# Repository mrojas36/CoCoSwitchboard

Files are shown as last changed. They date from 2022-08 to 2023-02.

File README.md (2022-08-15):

# CoCoSwitchboard
Membrane Replacement for TRS-80 Color Computer Keyboards

## Color Computer 3 Switchboard
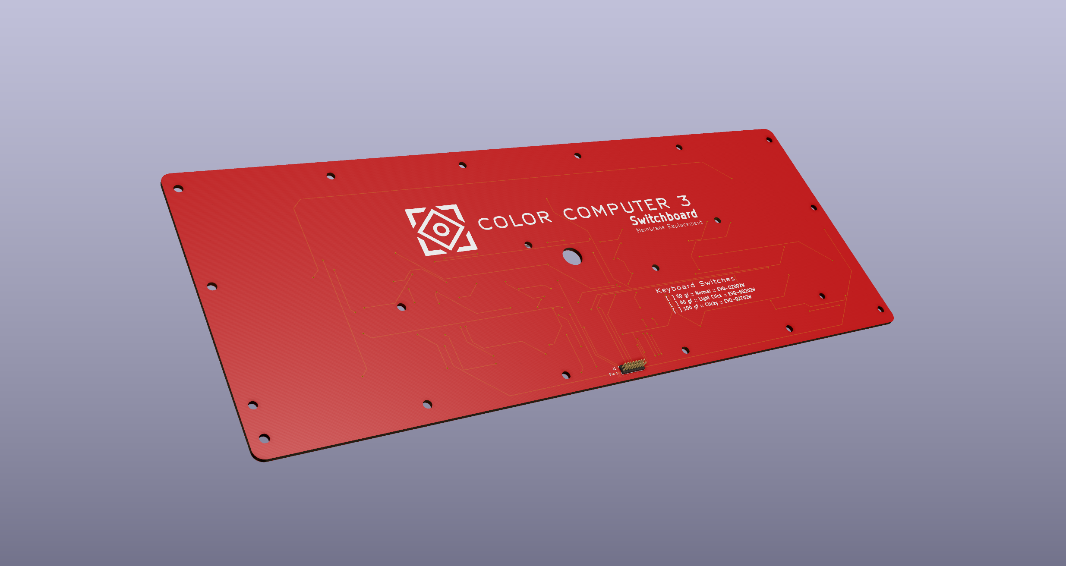
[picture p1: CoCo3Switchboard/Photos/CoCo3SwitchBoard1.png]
CoCo3Switchboard

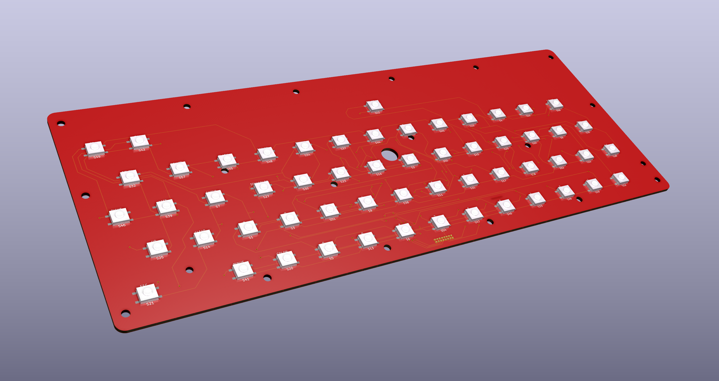
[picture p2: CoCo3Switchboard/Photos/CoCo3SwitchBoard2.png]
CoCo3Switchboard


## Color Computer 2 Switchboard
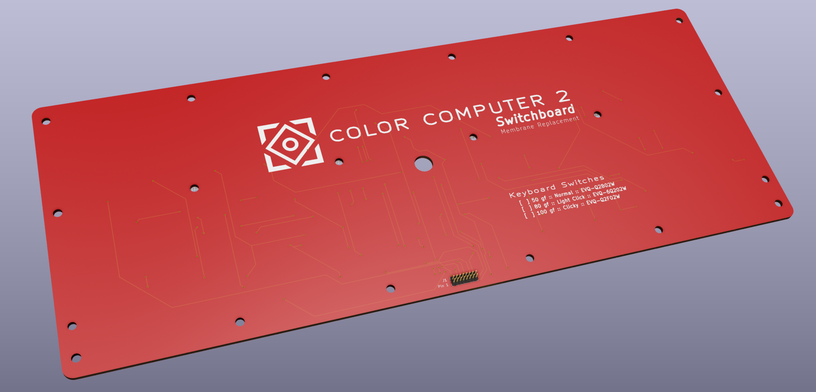
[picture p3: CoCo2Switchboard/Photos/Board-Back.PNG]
CoCo2Switchboard

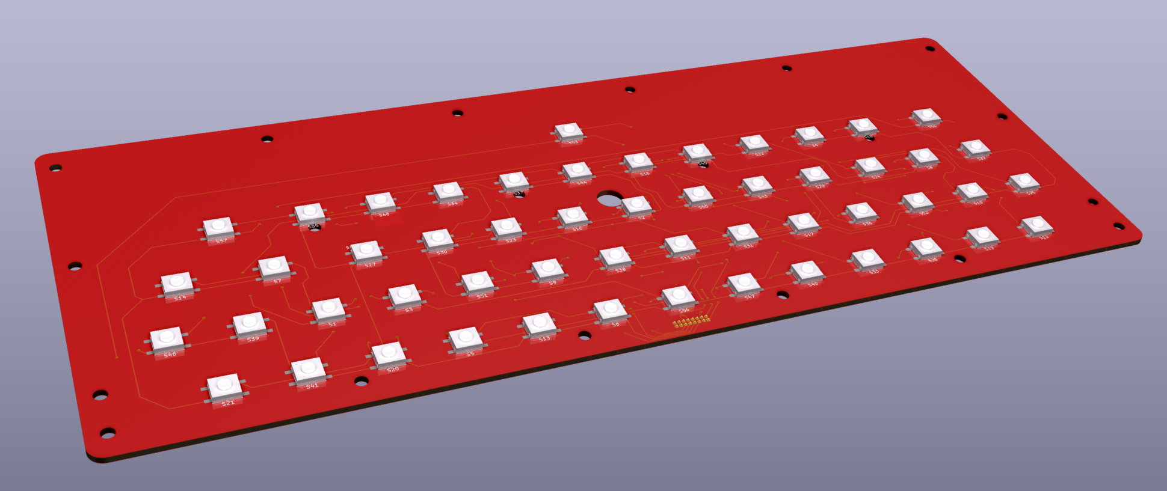
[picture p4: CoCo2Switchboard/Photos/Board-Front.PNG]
CoCo2Switchboard


## Color Computer 1 Switchboard
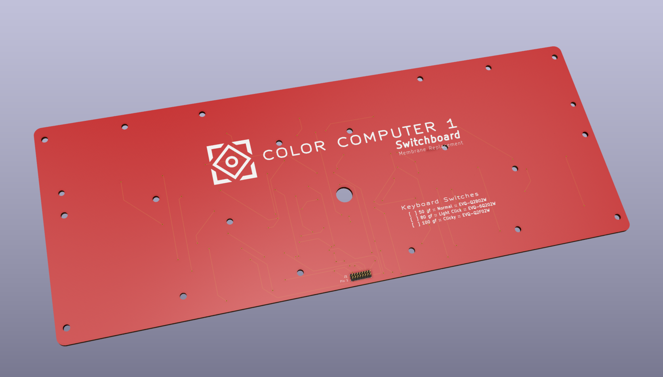
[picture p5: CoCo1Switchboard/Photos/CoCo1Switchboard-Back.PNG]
CoCo1Switchboard

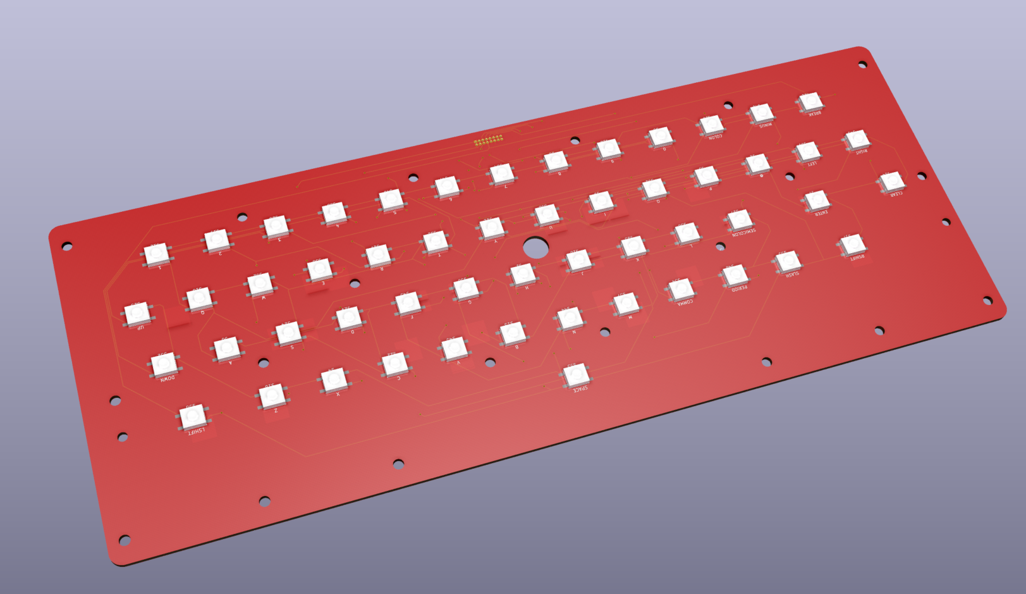
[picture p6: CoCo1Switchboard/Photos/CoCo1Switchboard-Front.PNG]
CoCo1Switchboard


## Keyboard Adapter
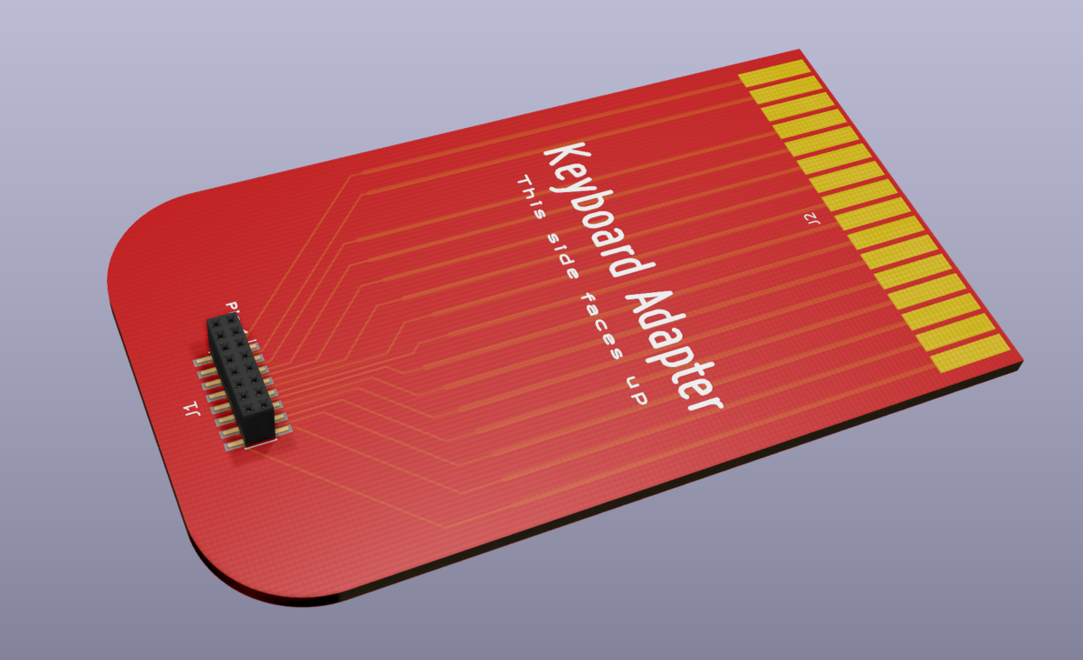
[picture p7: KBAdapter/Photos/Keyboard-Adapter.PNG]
Keyboard Adapter


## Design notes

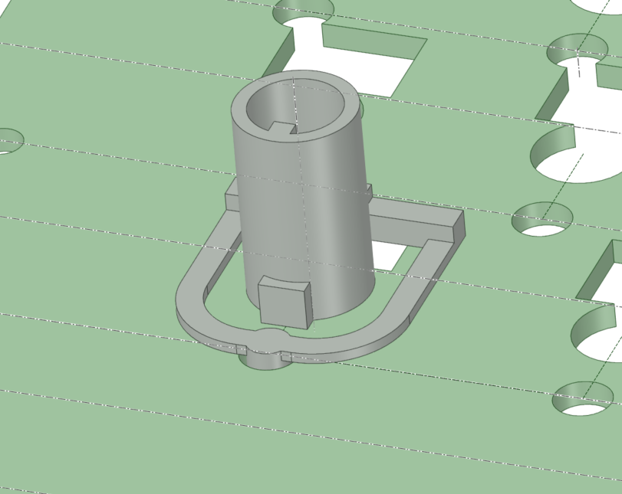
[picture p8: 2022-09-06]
CoCo3Switchboard/Photos/New-Spacer-Design.png

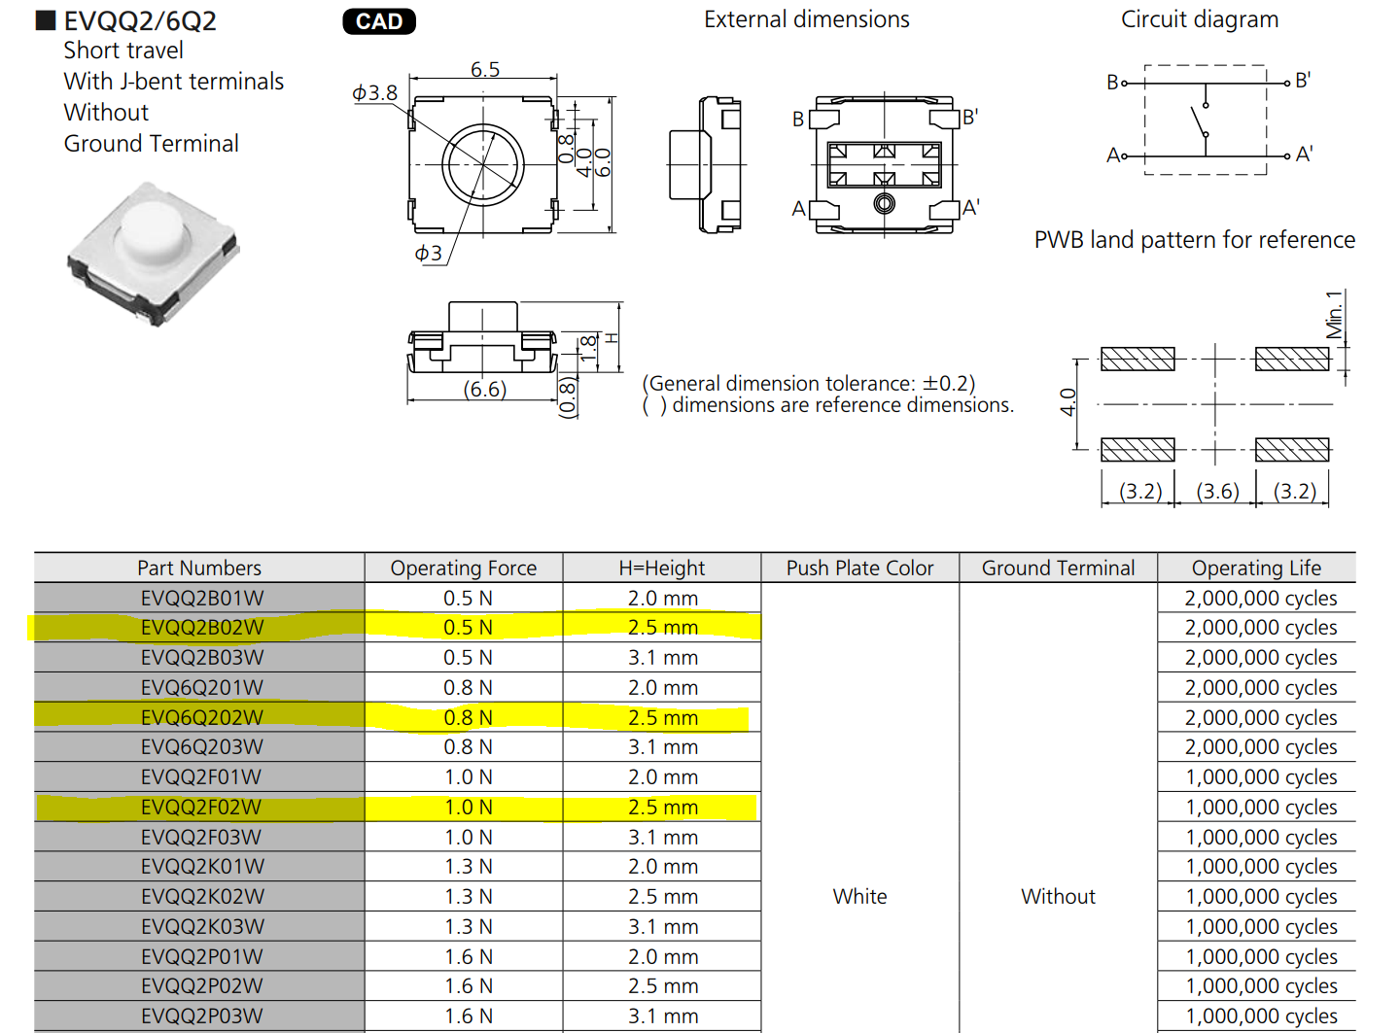
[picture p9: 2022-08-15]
CoCo3Switchboard/Photos/Switches.PNG

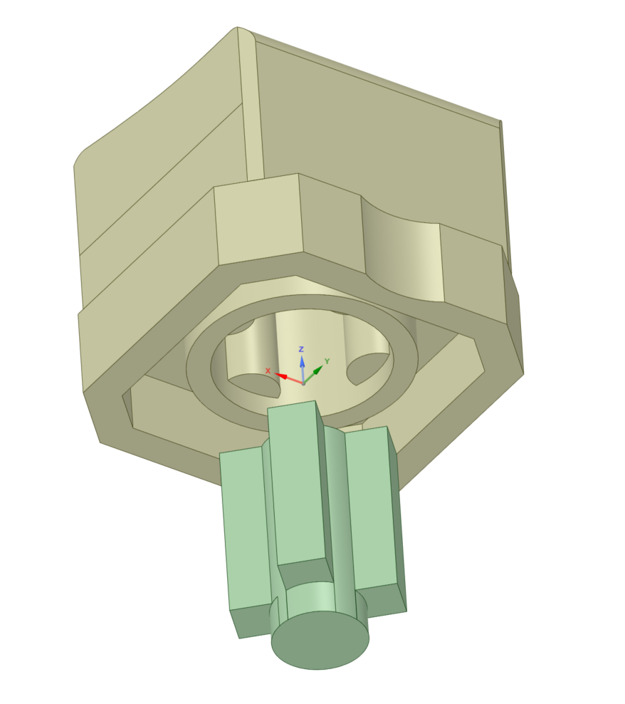
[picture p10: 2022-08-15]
CoCo1Switchboard/Photos/Key-Post-Not-Inserted.PNG

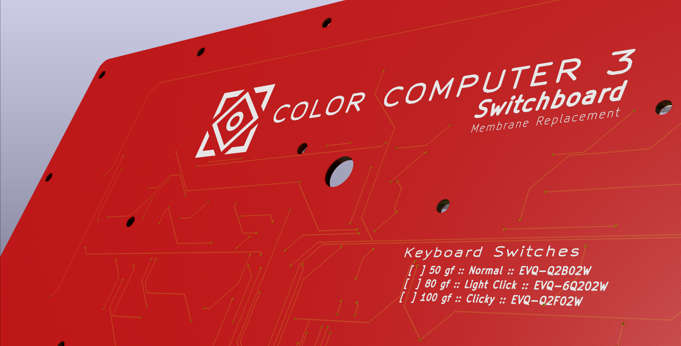
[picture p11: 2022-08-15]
CoCo3Switchboard/Photos/CoCo3SwitchBoard7.png

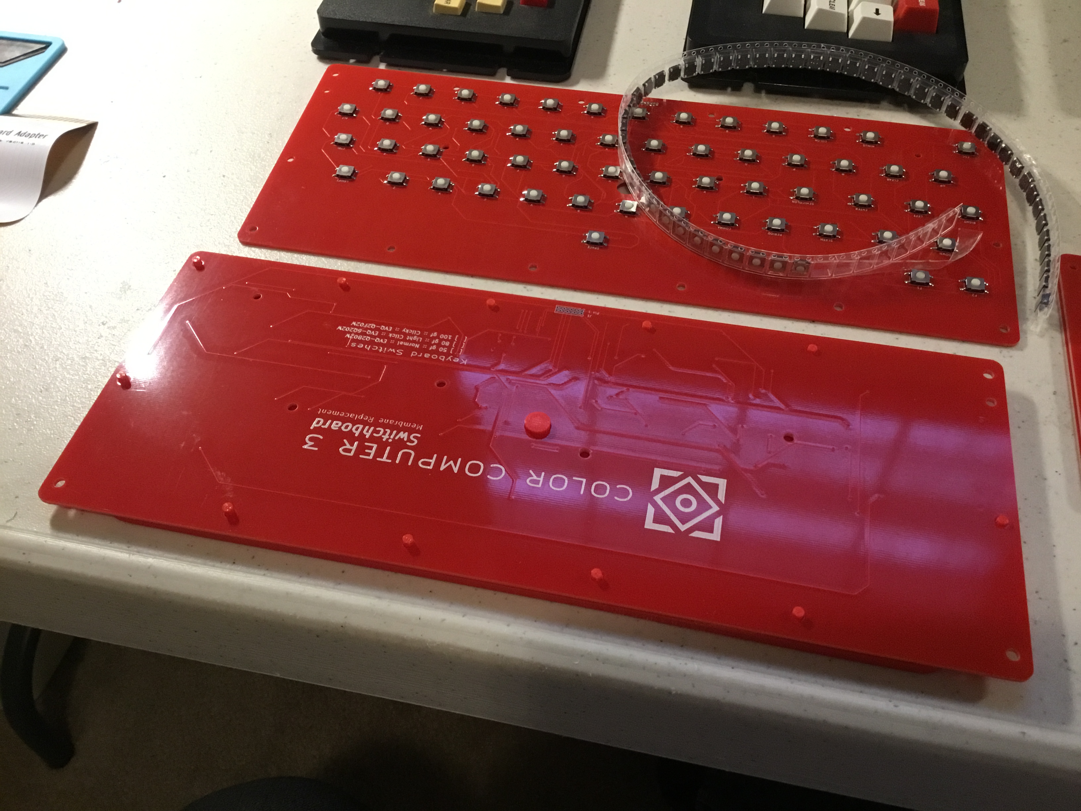
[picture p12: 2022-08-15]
CoCo3Switchboard/Photos/Jib3.JPG

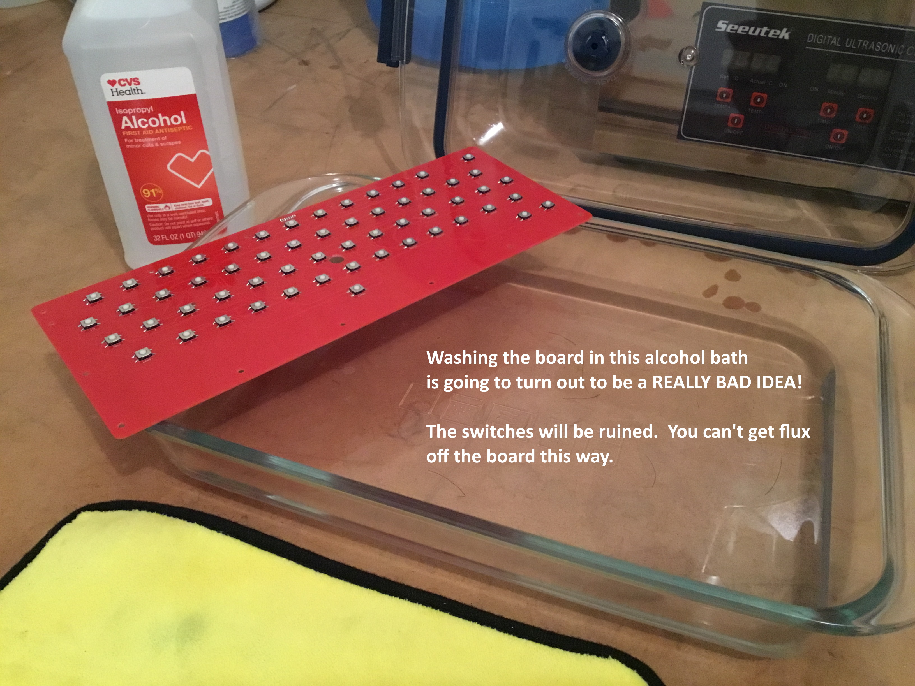
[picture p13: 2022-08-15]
CoCo3Switchboard/Photos/Wash.JPG

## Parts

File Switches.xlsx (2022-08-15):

Index | Quantity | Part Number | Manufacturer Part Number | Description | Customer Reference | Backorder | Unit Price | Extended Price | Force | Total | 57
1 | 10 | EG4620CT-ND | TL3315NF100Q | SWITCH TACTILE SPST-NO 0.05A 15V |  | 0 | 0.144 | $1.44 | 100gf | 8.208
2 | 10 | CKN10879CT-ND | PTS530 GN055 SMTR LFS | SWITCH TACTILE SPST-NO 0.05A 12V |  | 0 | 0.208 | $2.08 | 100gf | 11.856
3 | 10 | CKN10777CT-ND | KXT 311 LHS | SWITCH TACTILE SPST-NO 0.02A 15V |  | 0 | 0.211 | $2.11 | 100gf | 12.027
4 | 10 | P12937SCT-ND | EVQ-Q2F03W | SWITCH TACTILE SPST-NO 0.02A 15V | 3.1mm | 0 | 0.272 | $2.72 | 100gf | 15.504
5 | 10 | P12970SCT-ND | EVQ-Q2F02W | SWITCH TACTILE SPST-NO 0.02A 15V | 2.5mm | 0 | 0.272 | $2.72 | 100gf | 15.504
1 | 10 | P124393CT-ND | EVQ-6Q202W | 6MM SQUARE THIN TYPE SMD LTSW | 2.5mm | 0 | $0.23 | $3.98 | 80gf | 13.0359
2 | 10 | P12931SCT-ND | EVQ-Q2B02W | SWITCH TACTILE SPST-NO 0.02A 15V | 2.5mm | 0 | $0.23 | $2.72 | 50gf | 13.2867
6 | 10 | CKN12218-1-ND | PTS526 SM08 SMTR2 LFS | TACT 5.2 X 5.2, 0.8 MM H, 160GF, |  | 0 | 0.112 | $1.12 | 160gf | 6.384
7 | 10 | 2508-R-667834CT-ND | R-667834 | SWITCH TACTILE, SPST-NO, 0.05A 1 |  | 0 | 0.141 | $1.41 | 163gf | 8.037
8 | 10 | 2508-R-667995CT-ND | R-667995 | SWITCH TACTILE, SPST-NO, 0.02A 1 |  | 0 | 0.179 | $1.79 | 163gf | 10.203
9 | 10 | CKN10809CT-ND | PTS540JM035SMTRLFS | SWITCH TACTILE SPST-NO 0.05A 12V |  | 0 | 0.174 | $1.74 | 160gf | 9.918
 |  |  |  |  |  |  | Subtotal | $17.13
 |  |  |  |  |  |  |  |  | 57 | 0.154 | 8.778
 |  |  |  |  |  |  |  |  |  |  | 5.16
 |  |  |  |  |  |  |  |  |  |  | 13.938

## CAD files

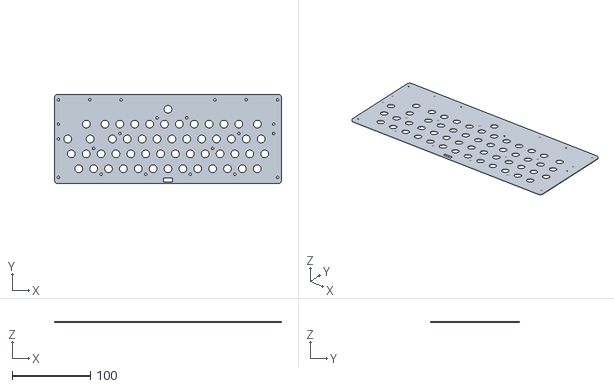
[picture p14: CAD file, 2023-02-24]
CoCo1Switchboard/Objects/Coco1-Spacer.stl
290.0 x 114.0 x 1.70

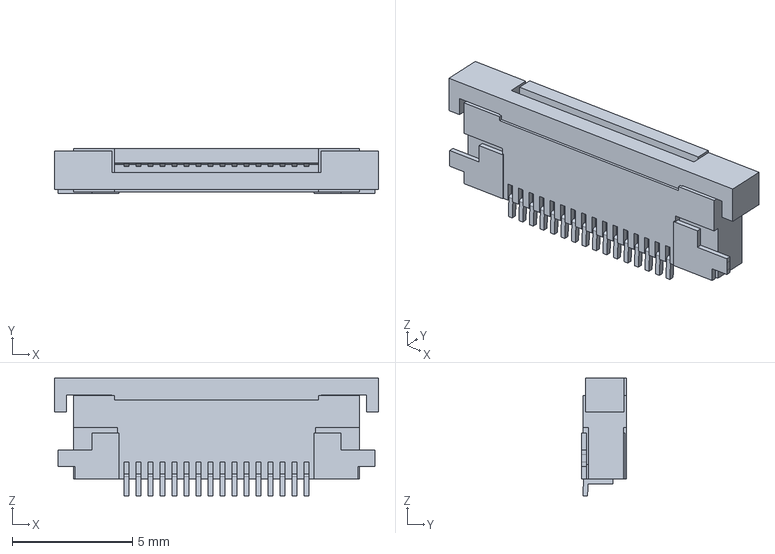
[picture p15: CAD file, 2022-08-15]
CoCo1Switchboard/ssfv16r_4stlf.stp
13.5 x 1.87 x 4.90 mm

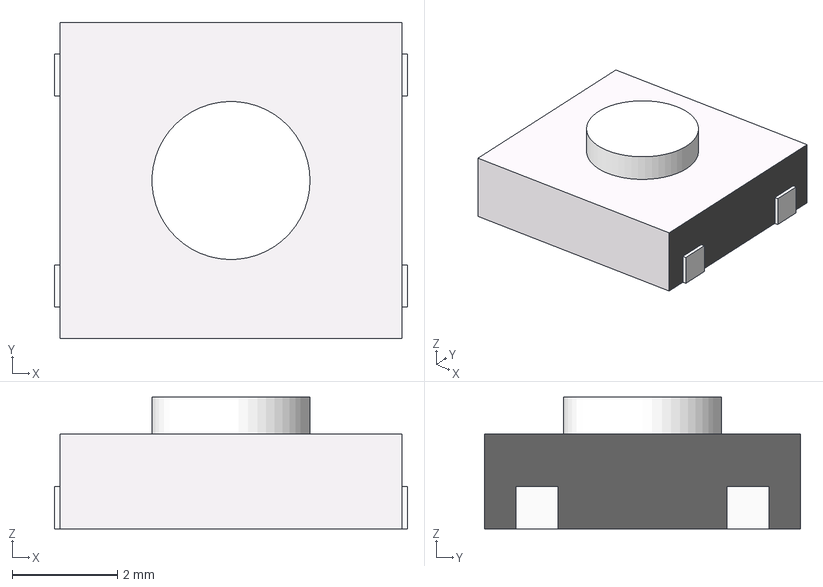
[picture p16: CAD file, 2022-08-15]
CoCo2Switchboard/Datasheets/EVQQ2-Switch.step
6.70 x 6.00 x 2.50 mm
Sketch
Plunger
Sketch002
SolderPad1
SolderPad2
SolderPad3
SolderPad4

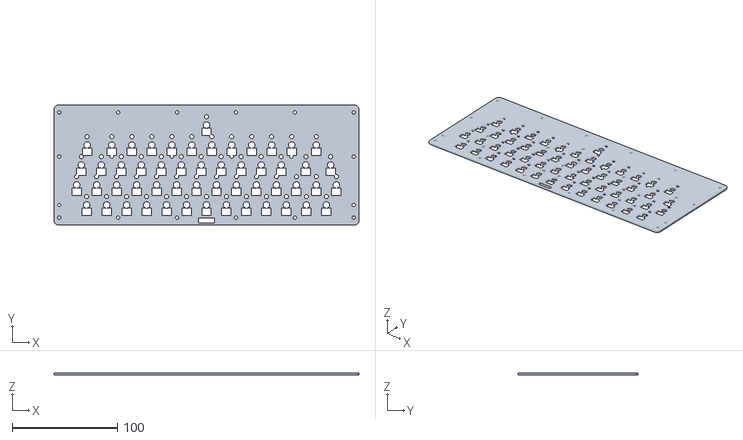
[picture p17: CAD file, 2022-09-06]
CoCo2Switchboard/Objects/Coco2Spacer-NewDesign.stl
290.0 x 114.0 x 1.80

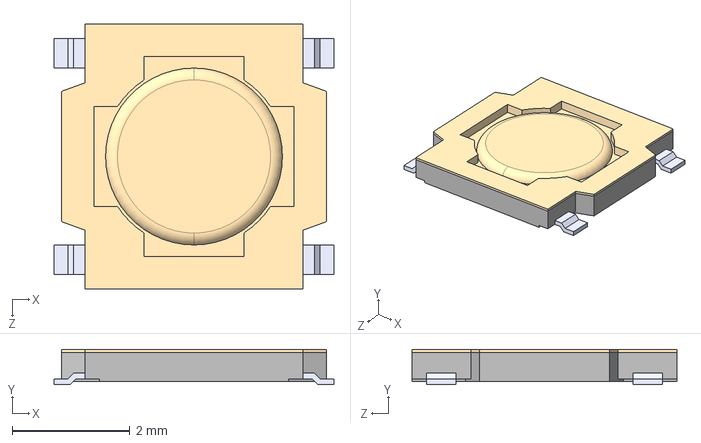
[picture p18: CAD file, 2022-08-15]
CoCo2Switchboard/TL3315NF100Q.step
4.75 x 0.6 x 4.50 mm

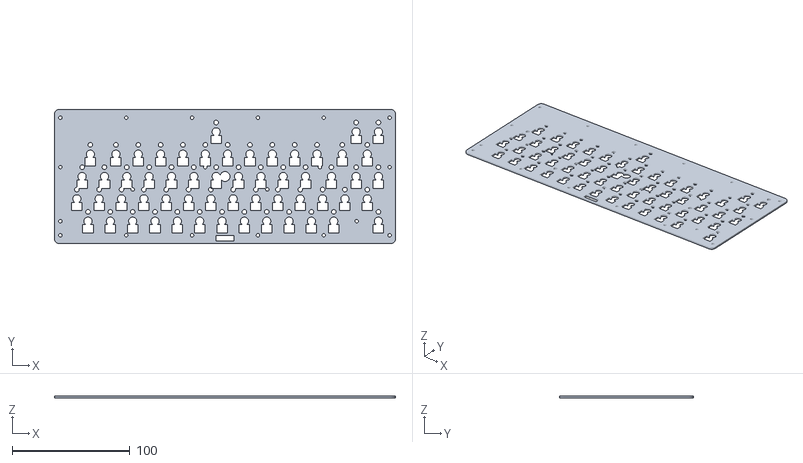
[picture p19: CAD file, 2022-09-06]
CoCo3Switchboard/Objects/Spacer.stl
290.0 x 114.0 x 1.80

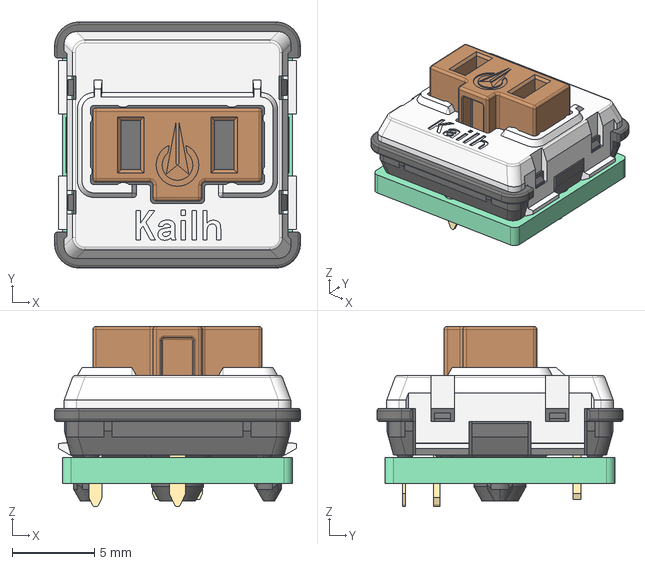
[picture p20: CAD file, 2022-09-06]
Designs/Kailh Choc Low Profile Switch.step
15.0 x 15.0 x 11.0 mm

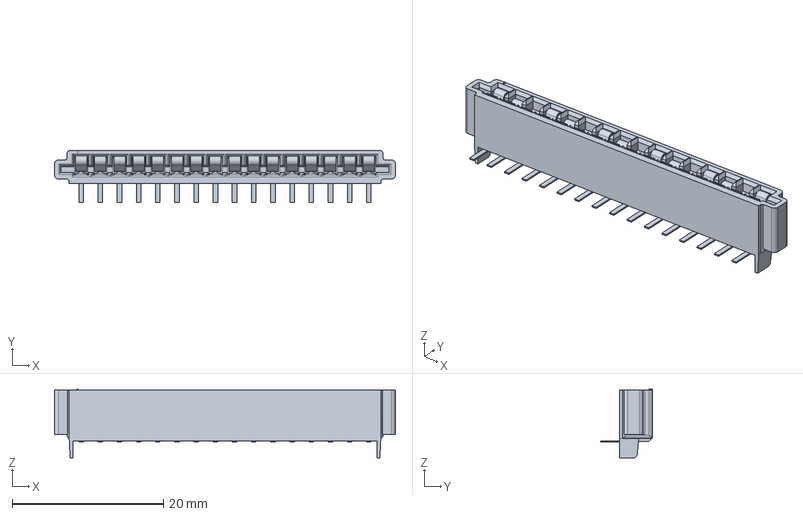
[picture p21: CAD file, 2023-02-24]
EdgeAdapter/c-6-520314-6-y-3d.stp
45.2 x 6.93 x 9.09 mm

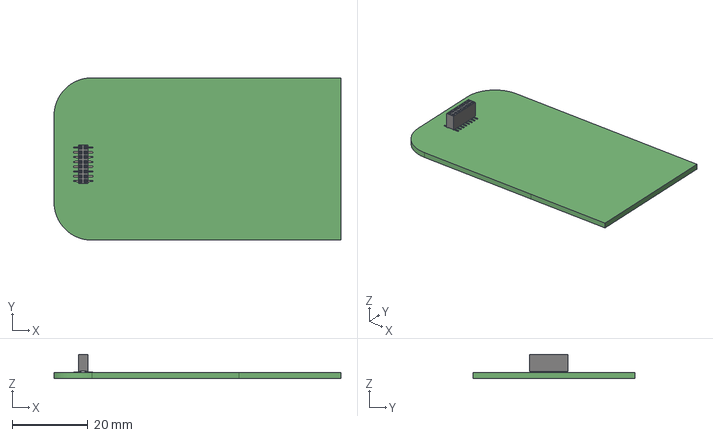
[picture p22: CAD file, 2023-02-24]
KBAdapter/KBAdapter.step
76.0 x 43.0 x 6.47 mm

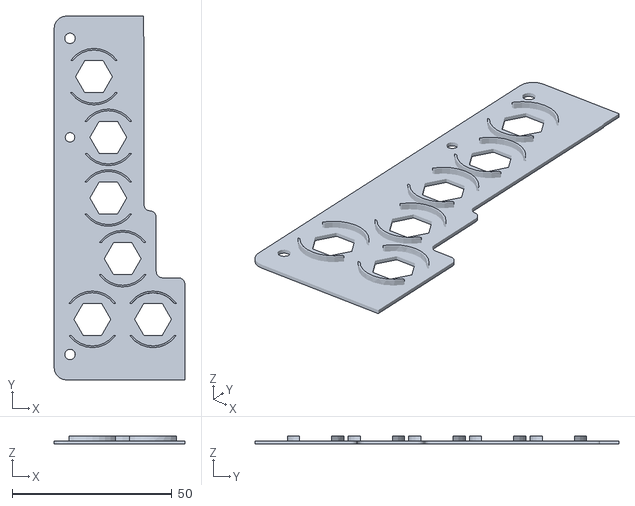
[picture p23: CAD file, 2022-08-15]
CoCo1Switchboard/Objects/TestPanel.stl
41.0 x 114.0 x 2.50

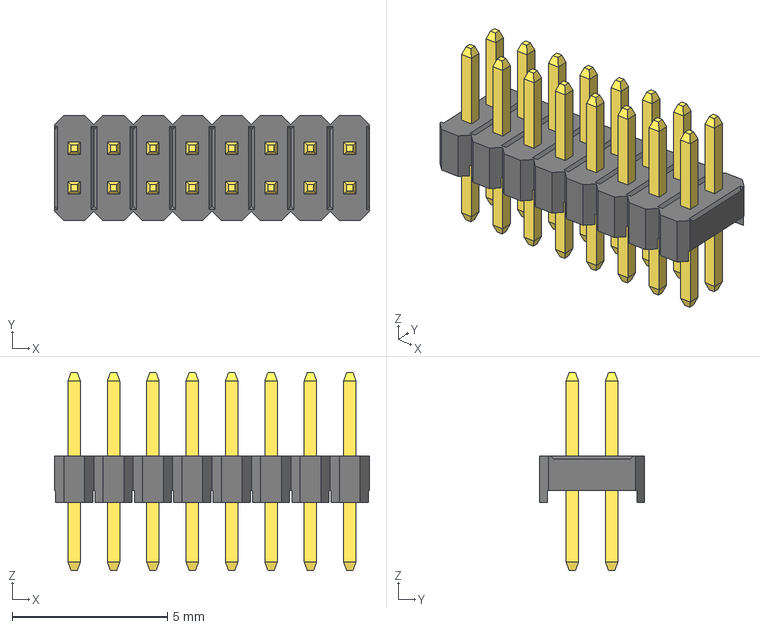
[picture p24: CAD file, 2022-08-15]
CoCo1Switchboard/PLLD-16.step
10.2 x 3.40 x 6.40 mm

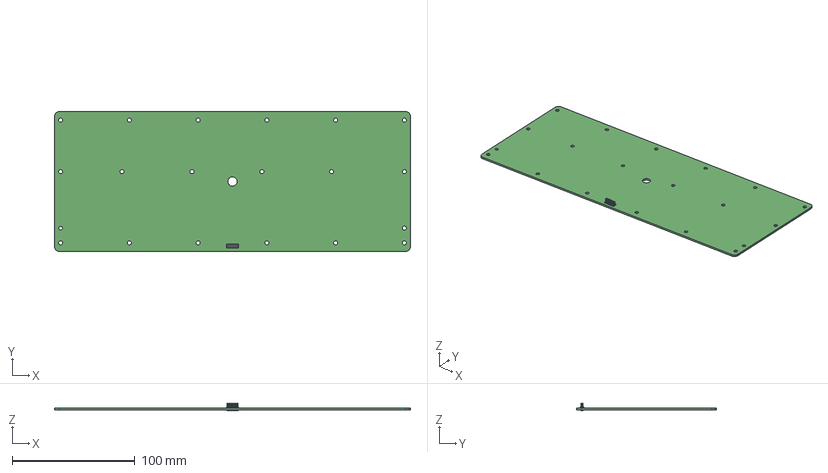
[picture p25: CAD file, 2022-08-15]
CoCo2Switchboard/CoCo2SwitchBoard.step
290.0 x 114.0 x 6.30 mm
EVQQ2-Switch x 53

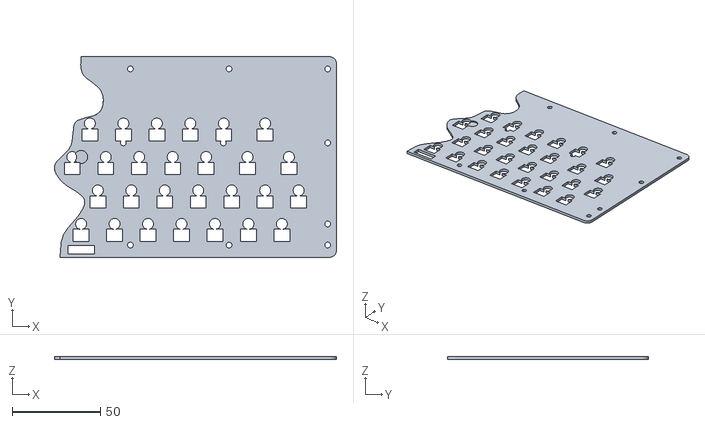
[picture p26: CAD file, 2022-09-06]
CoCo2Switchboard/Objects/Coco2Spacer-Left.stl
160.1 x 114.0 x 1.80

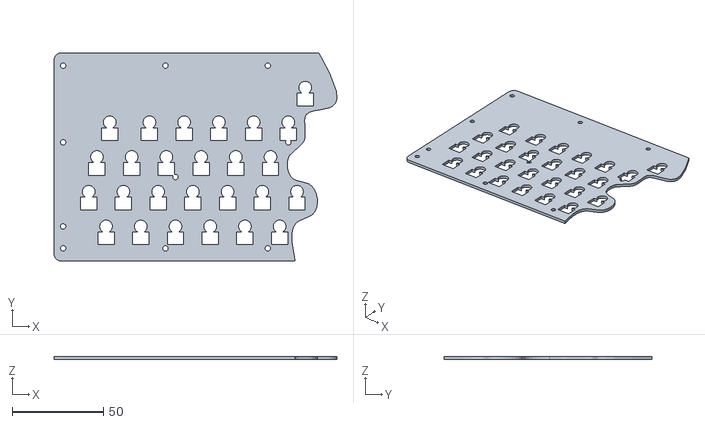
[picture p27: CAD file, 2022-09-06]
CoCo3Switchboard/Objects/Spacer-A.stl
154.9 x 114.0 x 1.80

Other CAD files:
CoCo1Switchboard/Objects/CoCo1-Left.stl
CoCo1Switchboard/Objects/CoCo1-Right.stl
CoCo1Switchboard/Objects/Coco1SwitchJig.stl
CoCo1Switchboard/Objects/EVQQ2-Switch.stl
CoCo1Switchboard/Objects/Post.stl
CoCo1Switchboard/Objects/TestPanelLeft.stl
CoCo1Switchboard/Objects/TestPanelRight.stl
CoCo1Switchboard/Objects/TestPost.stl
CoCo2Switchboard/Datasheets/EVQQ2-Switch.FCStd
CoCo2Switchboard/Objects/Coco2Spacer-Right.stl
CoCo2Switchboard/Objects/Coco2SwitchJig.stl
CoCo2Switchboard/Objects/EVQQ2-Switch.stl
CoCo3Switchboard/Datasheets/EVQQ2-Switch.FCStd
CoCo3Switchboard/Objects/Coco3SwitchJig-Test.stl
CoCo3Switchboard/Objects/Coco3SwitchJig.stl
CoCo3Switchboard/Objects/EVQQ2-Switch.stl
CoCo3Switchboard/Objects/Spacer-B.stl
Designs/Kailh Hotswap.step
Designs/Kailh Polia.step
EdgeAdapter/SSW-116-02-L-S-RA.step
Objects/Screw-Holder.stl

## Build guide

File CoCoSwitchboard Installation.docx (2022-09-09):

# CoCo Switchboard Installation

# Overview

Congratulations! You are about to become a Color Computer keyboard restorer. To successfully restore your failed keyboard membrane, I want to recommend some tips that I learned the hard way.

Key points:

- Work on a well-lit, flat surface with plenty of space.
- Get some plastic cups to hold your keyboard parts, like springs and screws.
- Get a couple of supports (like plywood or books) to prop up your keyboard while you work on it.
- A Philips screwdriver that fits small screws. No power tools.
- Take your time.
- Use the backward-first technique for inserting screws (see below).

GitHub Materials: https://github.com/mrojas36/CoCoSwitchboard

# Working on 40-year-old Plastic

IMPORTANT: The chassis of your keyboard is plastic. Ancient plastic. It is delicate and you can ruin it if you are not careful. The most important thing to understand is that when your keyboard was assembled, screws were driven into the plastic creating the grooves that your screws now sit in. It is important that your new screws use the same grooves. You do NOT want to create new ones. Two sets of grooves will just create a stripped-out hole and the screw will not hold anymore.

So how do you make sure your screw goes into the existing grooves?

Easy. Use the “backwards first” technique. Here is how it works.

1. Place screw into hole.
2. Using your screwdriver, slowly turn the screw backwards (counterclockwise) while applying gentle pressure.
3. While turning backwards, you will feel the screw drop and “click”. That is when you know your screw has realigned with the original grooves.
4. Now you can turn the screw clockwise and gently tighten until it stops. Do not over tighten.

You can use the screw holder that was shipped with the kit to practice. Once you get the hang of it, congratulations – you are a restoration master!

# Step 1 – Remove your keyboard

Open your Color Computer by removing the screws on the bottom of your case. There should be six screws on most machines. Remember, the long screws will go in the back. Place the case screws into one of your plastic cups for safe keeping.

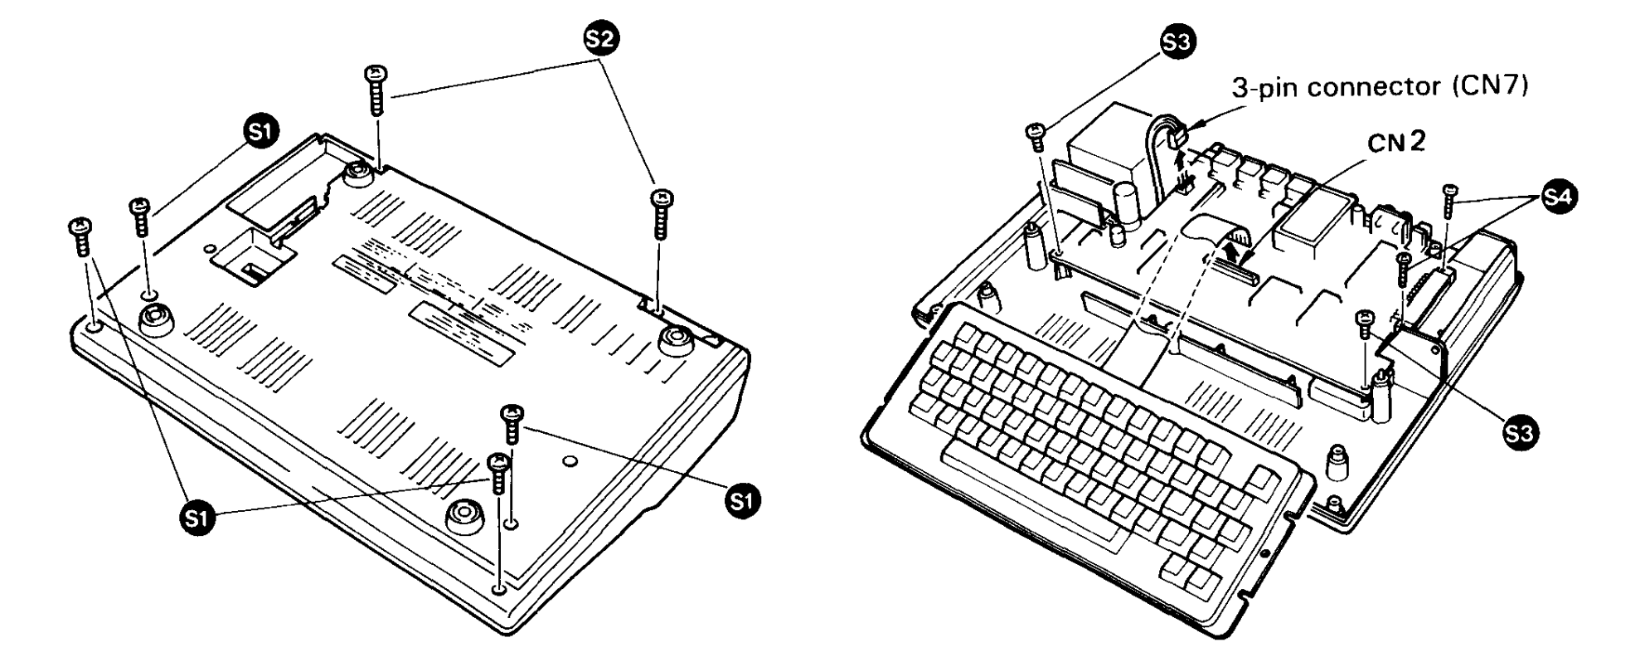
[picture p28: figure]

Pull the flexible flat cable out of CN2 by pulling straight up. If it is stuck, try rocking it left and right until it pulls free. We now have your keyboard removed. Set your keyboard aside for the moment.

# Step 2 – Connect the Keyboard Adapter

You should test that only your membrane has failed. You can do that by connecting the keyboard adapter to your new switchboard and temporarily installing the assembly into your computer. Hold the board so you can see the pin header and press the connector in, making sure both rows of pins mate properly.

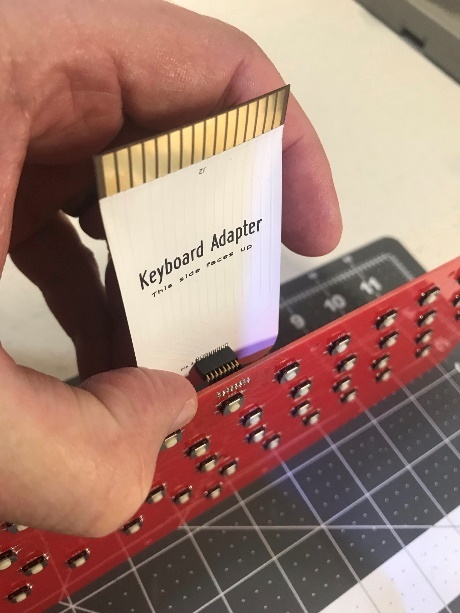
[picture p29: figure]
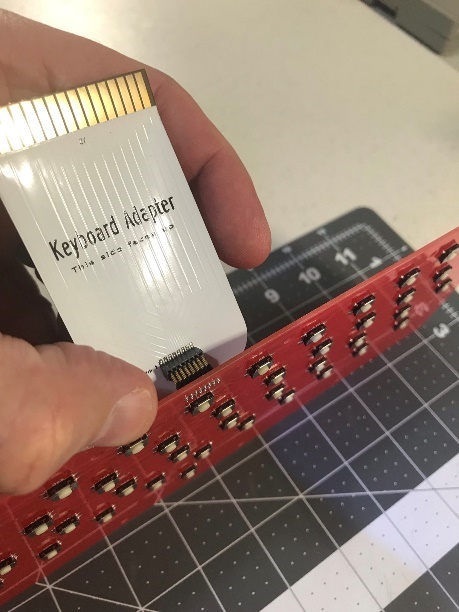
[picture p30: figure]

# Step 3 – Test your Switchboard

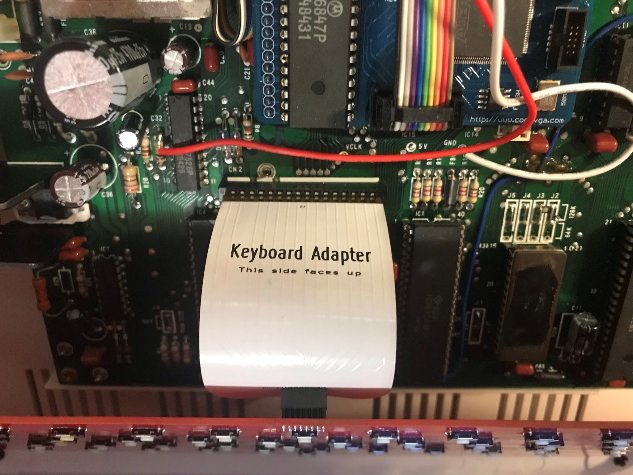
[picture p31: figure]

Install the assembly into your computer with the top case off. Insert the keyboard adapter into connector CN2 on your motherboard, like this:

You can prop up the switchboard like this:

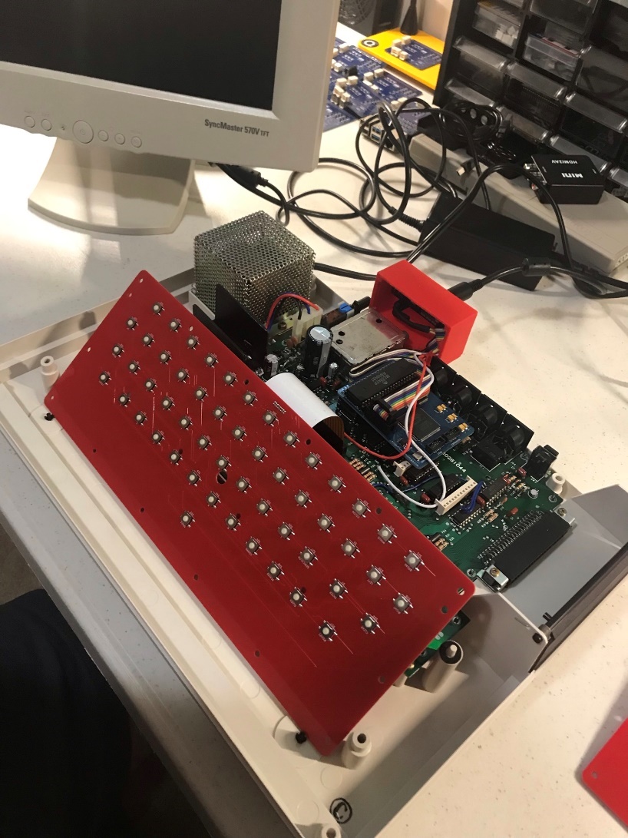
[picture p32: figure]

Power up your computer and press every key. Make sure you try the shift keys as well. Your switch board and keyboard adapter were tested in a real machine before it was shipped. If keys are not working, it is possible you have other damage that needs repaired.

Examples include:

- Failed PIA chip
- CN2 connector is bad or oxidized
- Trace damage on your motherboard

Resolve these issues before continuing.

If things look good, let’s swap it into your actual keyboard.

IMPORTANT: If you are a Color Computer 1 or 3 owner, you can skip to step 5. If you are a Color Computer 2 owner, proceed to the next step.

# Step 4 – Test fit Switchboard on your computer.

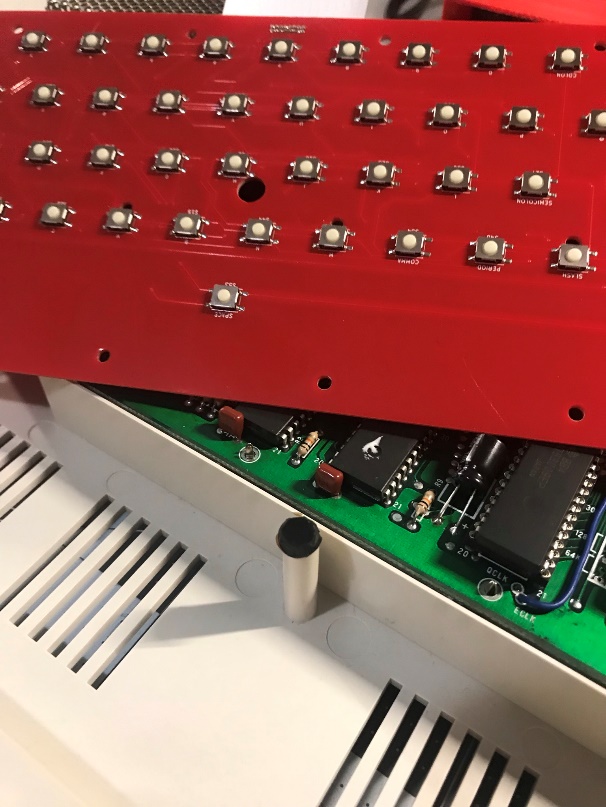
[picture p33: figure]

Notice that the board has a hole in the center. This is meant to align with the middle support post in your computer. On a Color Computer 1 and Color Computer 3, the center support post will rest inside the cavity made by the hole and the spacer.

On a Color Computer 2, the hole will be too small. This is because there is a switch that will not allow the center hole to be larger. Because of this, you will need to trim down the diameter of the rubber support in the center post.

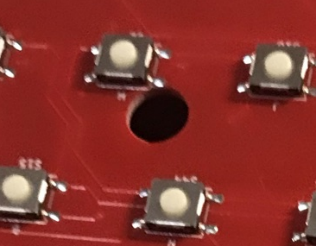
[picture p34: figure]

This rubber post will need trimmed.

You can trim it down from the top – taking a bit of rubber off the top but this will be irreversible. This means the support will be too short if you decide to put the old membrane back. Or you can trim the diameter like I did. This will be reversible – meaning the old membrane could be put back.

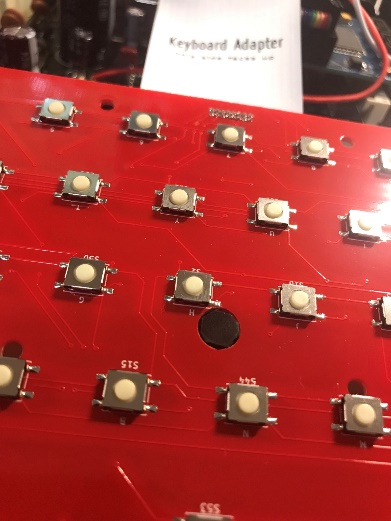
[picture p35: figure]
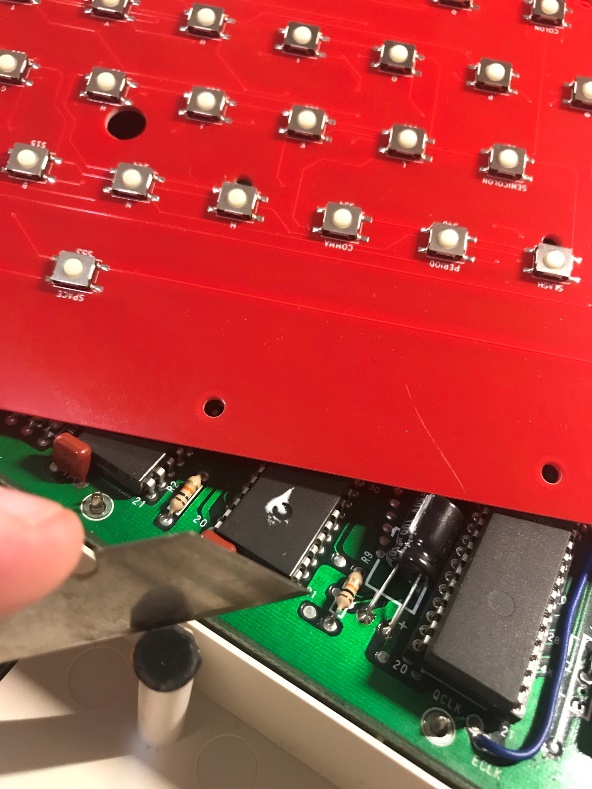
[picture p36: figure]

To change the diameter of the rubber support, take a razor blade and carefully trim around the post. Try to make little slices by holding the razor blade vertically and pressing down until you hit the plastic. Continue around the post until you have trimmed every side.

You should be able to fit the rubber part of the support into the hole when the diameter is small enough.

# Step 5 – Remove your Old Membrane

Get a pair of supports to prop up your keyboard like this:

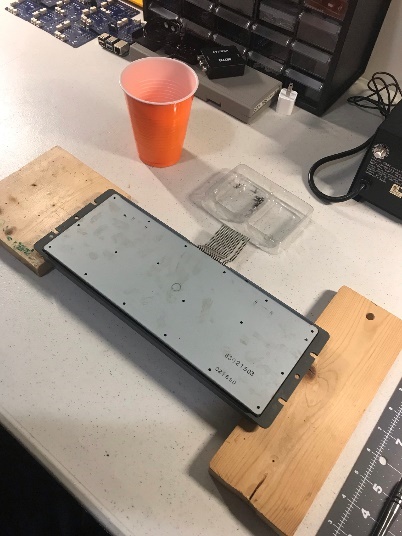
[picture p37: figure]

The important thing is to make sure your keys can hang suspended and not depressed. You are now ready to remove the back plate. Color Computer 2 and Color Computer 3 will have 18 screws to remove. A Color Computer 1 has 20. Save your old screws in case you want to reverse this process.

Use a plastic cup or some other container to hold the screws.

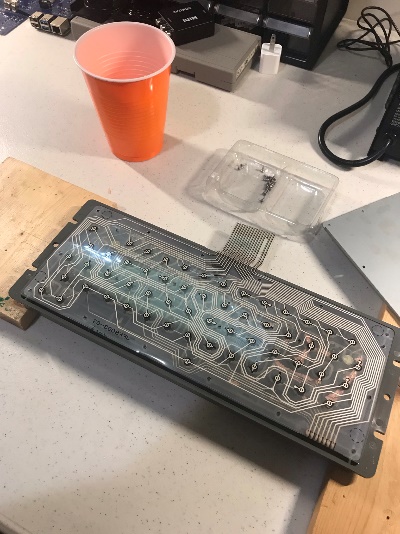
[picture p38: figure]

Now carefully remove the back plate, exposing the keyboard membrane. IMPORTANT: If your keyboard has suffered liquid damage, it is possible that the back plate will have become glued to the membrane. Remove slowly and take care to pull it apart in a way that will NOT send your springs flying!

Set the back plate aside. You will not need the back plate or the membrane.

With the membrane exposed, carefully remove the membrane taking care to not lose your springs!

Set it aside as well.

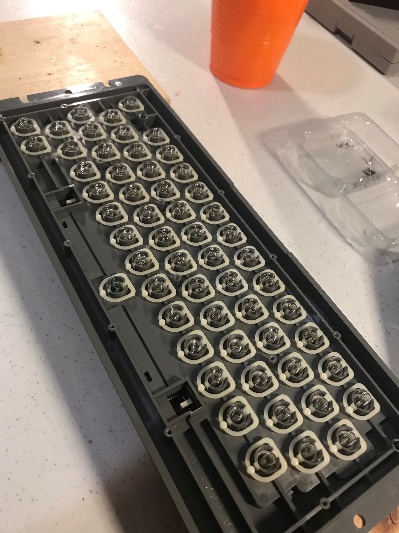
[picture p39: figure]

With the membrane off, look closely and make sure you have all your springs. A Color Computer 1 has rubber domes instead of springs. Make note that the space bar has a different color spring because it needs a different level of force. If you take out your springs, make sure you put that different color spring back into the space bar key.

TIP: Now would be a great time to remove every spring and then wash your keyboard. If it has liquid damage, giving it a good clean will go a long way. Some people even get a keyboard puller (just google it) and remove every key, hand washing each one. Some even retrobrite the keys to remove the yellowing.

# Step 6 – Install the Spacer and Switchboard

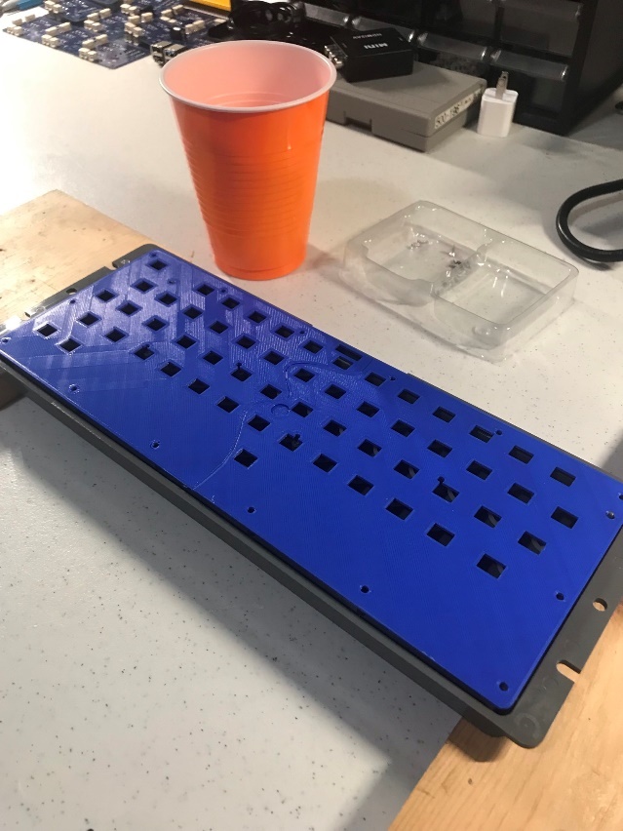
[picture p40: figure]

The switches need to be positioned so they do not interfere with the travel of the keys. The spacer accomplishes this task. The spacer will arrive in two pieces. It can only be installed one way, but in the center of the spacer you will see a small round indentation. This will align with the hole in the center of the switchboard.

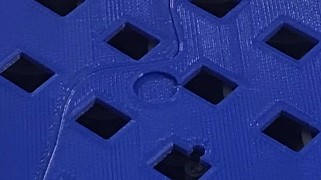
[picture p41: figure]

The spacer will also align with the two keyboard posts on each side of the board.

Important: You need to be careful when placing the spacer and switchboard on top of your keyboard. It is important that everything lines up nicely with your keys. Place the spacer down as centered as possible, then place the switch board on top, making sure the switches fit into the openings on the spacer.

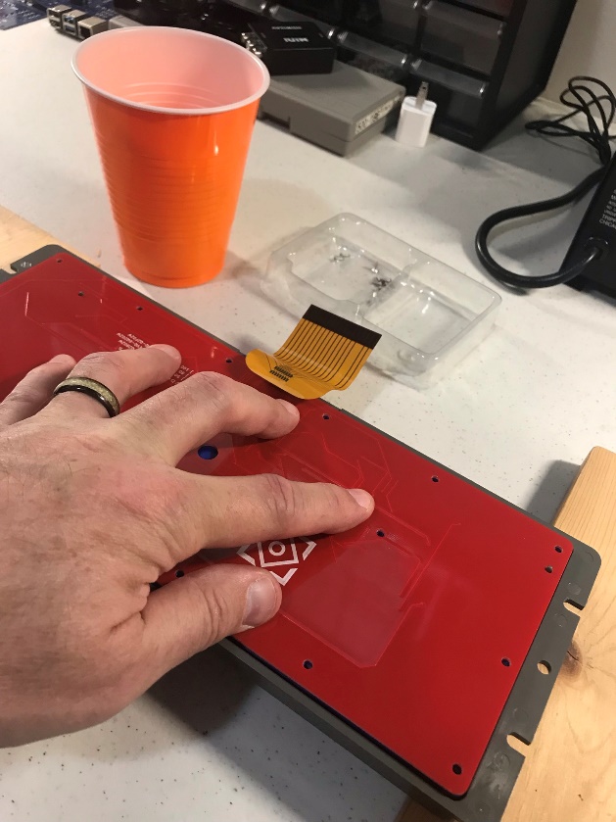
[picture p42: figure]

When you think you have everything aligned, you can now begin the assembly.

To assemble the board, you will need to press down on the board, compressing the springs, and placing the screws into the board with your other hand. You should start in the center and work towards the edges of the keyboard.

You are now ready to begin inserting the new screws (provided in the kit) into the switchboard.

Take your time and do one screw at a time.

You will have to use the screws provided in the kit. Your original screws will be too short to go back in.

Remember to use the “backwards first” technique!

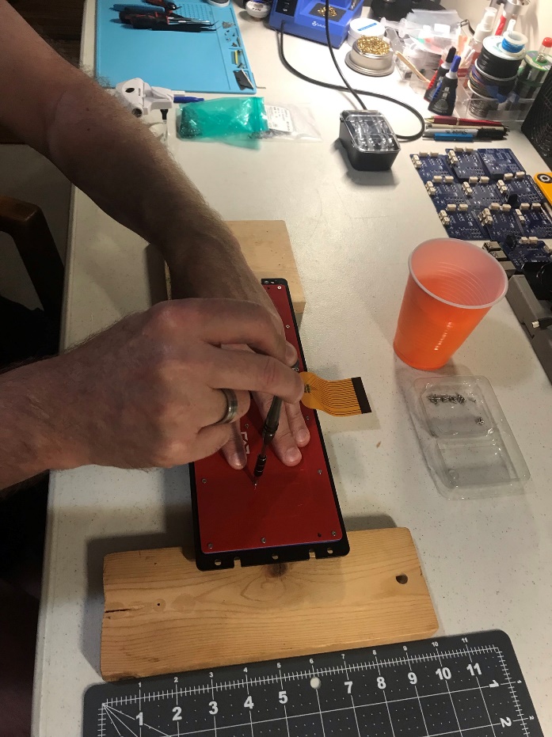
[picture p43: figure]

When you are installing the screws, make sure you are applying enough pressure to compress the springs. I used one hand to apply pressure and the other hand to put the screws in:

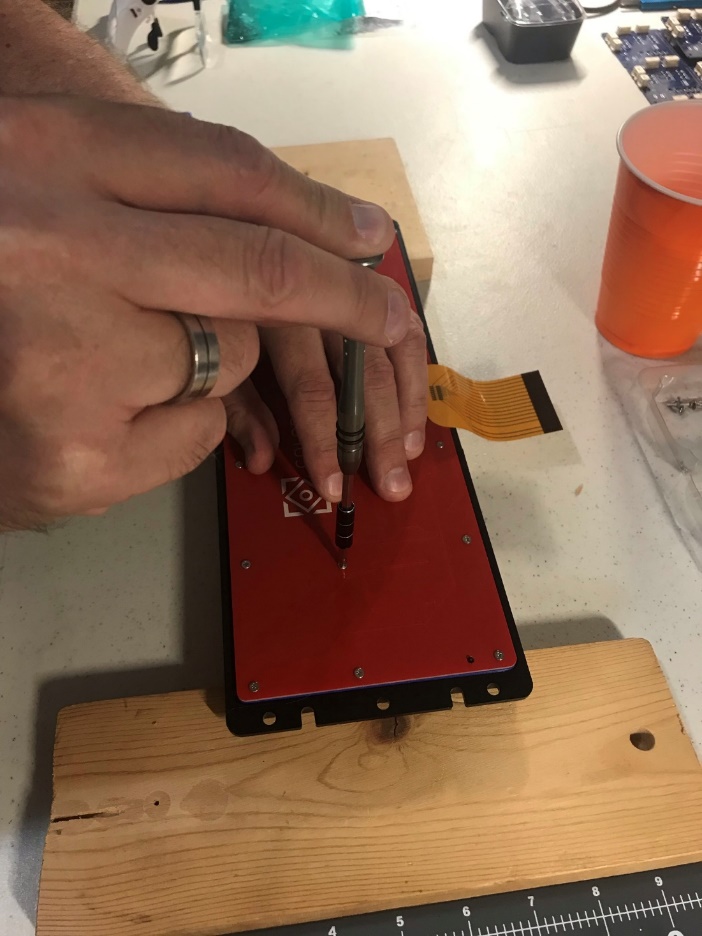
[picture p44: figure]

I worked my way from the center to the edges. Make sure you do not over-tighten the screws.

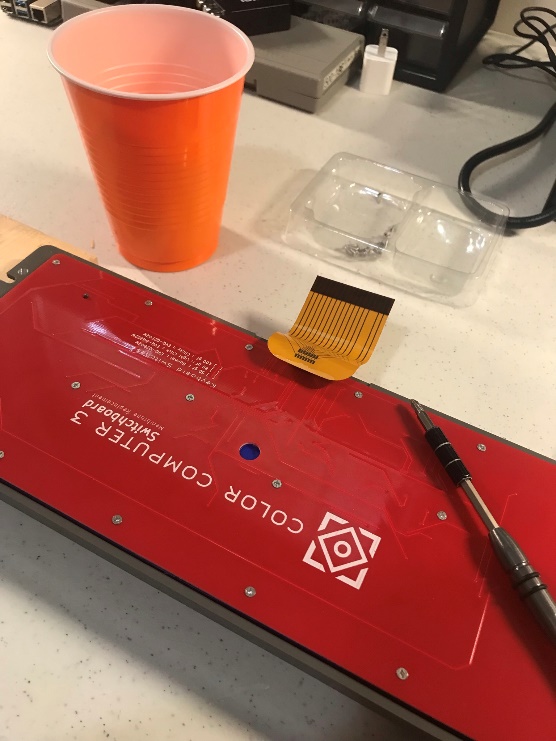
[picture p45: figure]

The hard part is now done!

# Step 7 – Install the keyboard back into your computer

Notice that the board has a hole in the center. This is meant to align with the middle support post in your computer. On a Color Computer 1 and Color Computer 3, the center support post will rest inside the cavity made by the hole and the spacer.

On a Color Computer 2, the hole will be too small. But you would have fixed this in step 4.

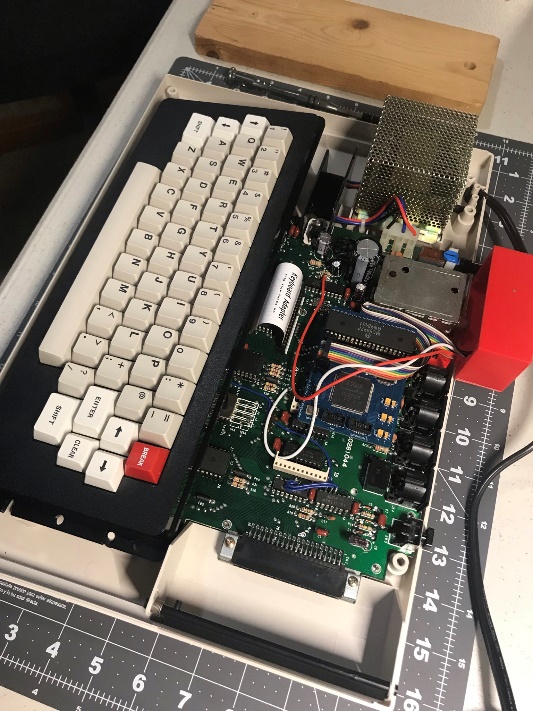
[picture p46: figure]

Set the keyboard back on its support posts and gently insert the keyboard adapter into the connector CN2.

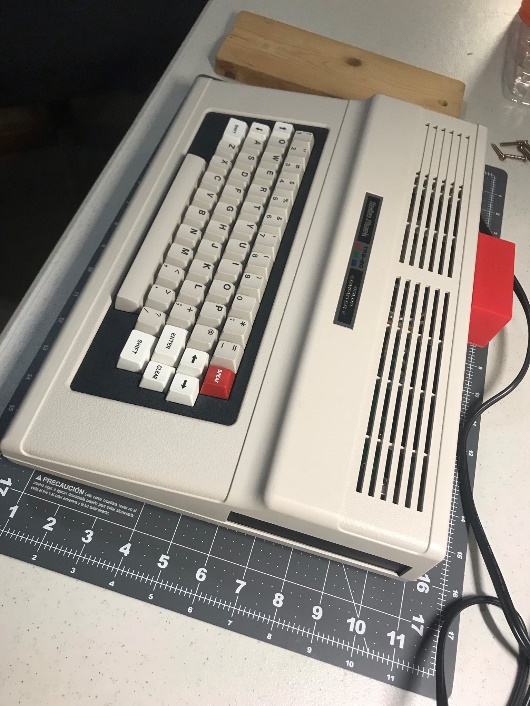
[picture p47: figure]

Put your case screws back in.

Sit back and enjoy your handiwork. Nice work!

# New Spacer – Errata

The old spacer design had a few challenges. For one, it was 3D printed in two pieces making it had to get properly aligned. The new spacer aims to resolve that by printing the spacer as a single piece. In addition, we added a few new holes in the spacer: one to allow the springs to pass through and another to give the membrane “nub” a place to rest without interfering with the key action.

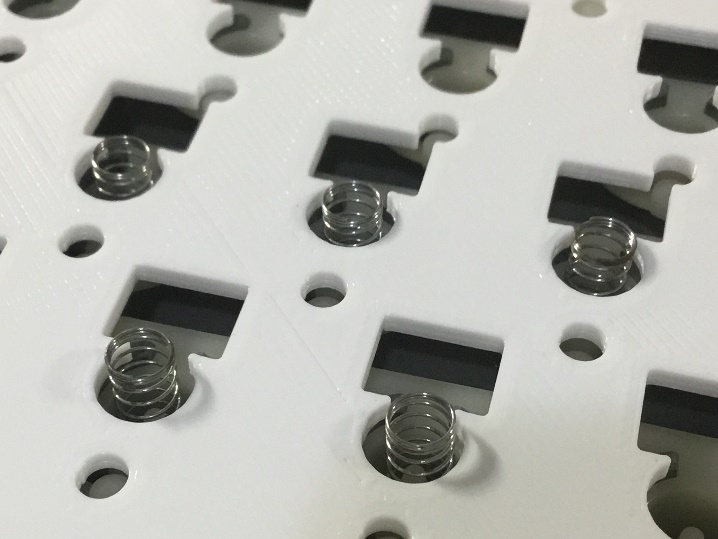
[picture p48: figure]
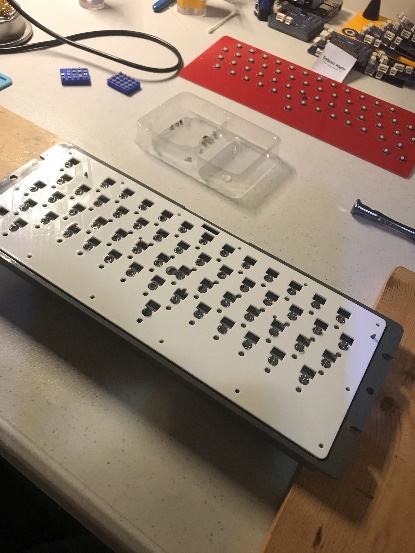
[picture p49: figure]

Hole for spring to pass through

Hole for “nub” to pass through

Using the new spacer is simple, however, here are a few tips:

- Remove your springs before attempting to place the spacer. The springs are in fact “springy” and if the hole of the spacer catches the spring they will go flying! I found removing the springs, placing them in a cup, then placing the spacer, and reinserting the springs works better.
- Key sticking. Sometimes the hole for the membrane “nub” has some PLA strings in it. These imperfections can sometimes catch the key and cause it to stick. Inspect the spacer before using. I suggest you try every key with the springs out and the spacer placed on top and held by hand. Hold the keyboard with the keys down and the spacer up. Now start pressing keys from the underside and look for sticking keys. You should be able to press the key and just let it drop back down.

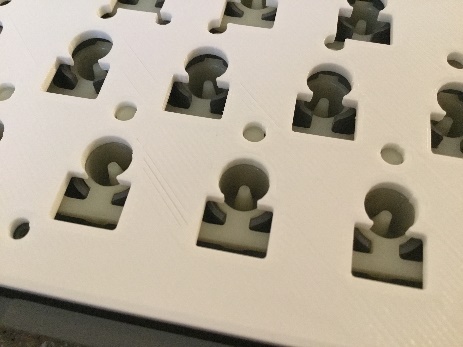
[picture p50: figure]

Eliminating the sticking key is easy, just round out the “nub” hole with a razor blade until the key no longer sticks.

Take a razor blade and round the hole that is causing the key to stick

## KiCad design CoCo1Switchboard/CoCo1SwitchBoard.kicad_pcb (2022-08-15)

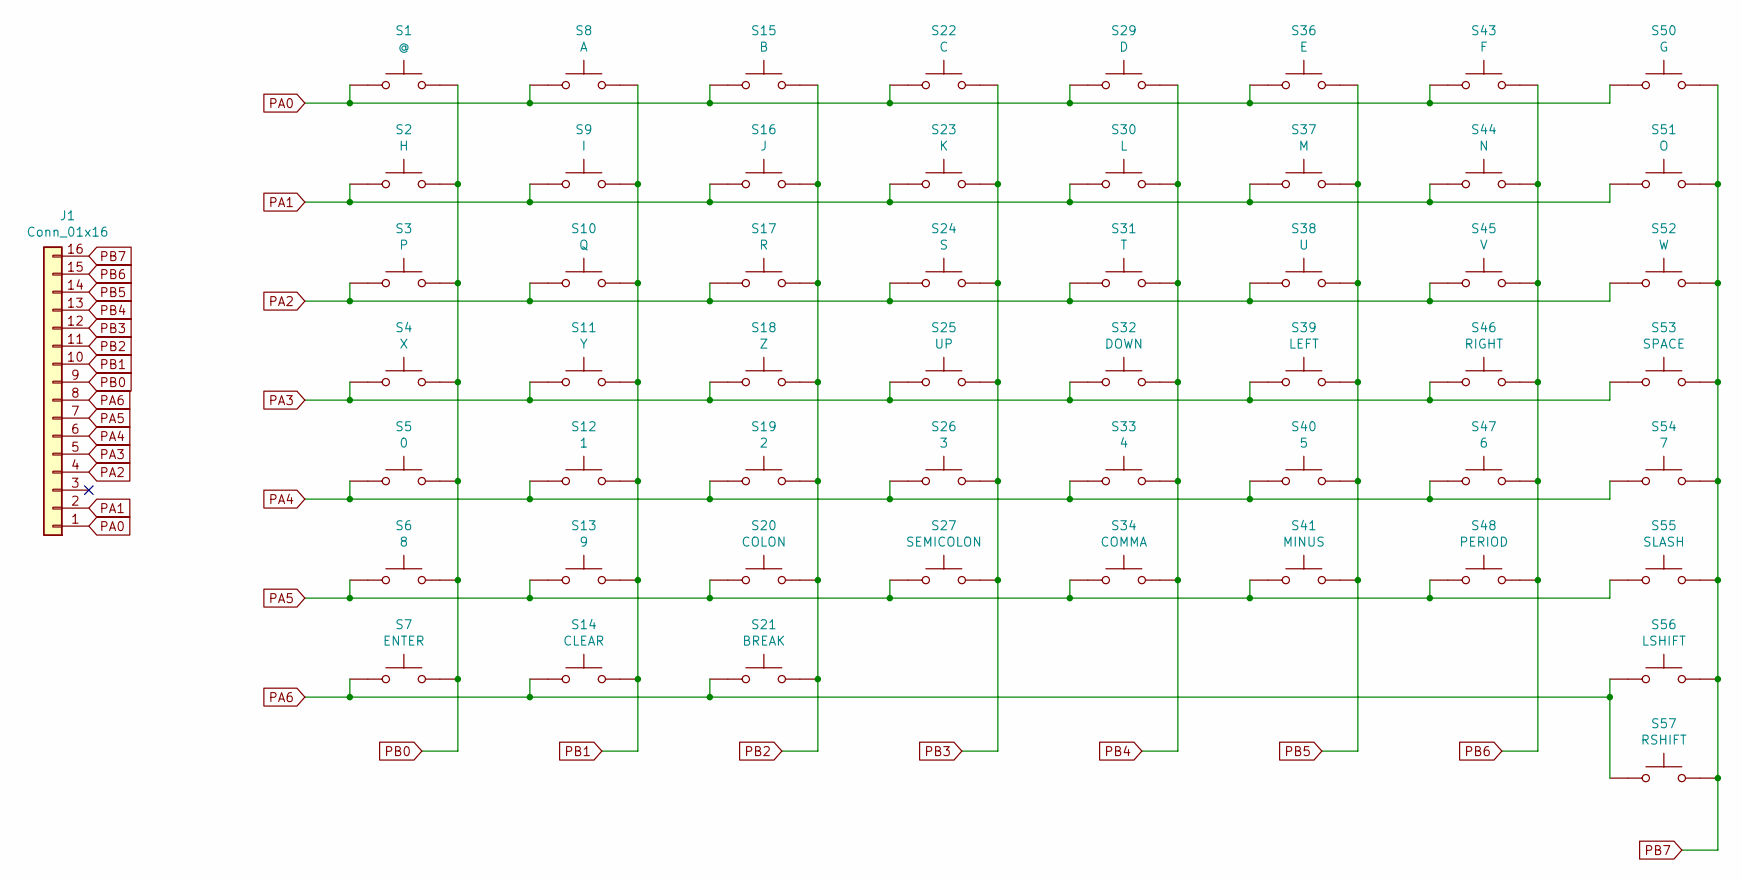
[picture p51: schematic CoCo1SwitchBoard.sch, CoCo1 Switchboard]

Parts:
J1: Conn_01x16; PinHeader_2x08_P1.27mm_Vertical
S1: @; SW_SPST_EVQQ2
S2: H; SW_SPST_EVQQ2
S3: P; SW_SPST_EVQQ2
S4: X; SW_SPST_EVQQ2
S5: 0; SW_SPST_EVQQ2
S6: 8; SW_SPST_EVQQ2
S7: ENTER; SW_SPST_EVQQ2
S8: A; SW_SPST_EVQQ2
S9: I; SW_SPST_EVQQ2
S10: Q; SW_SPST_EVQQ2
S11: Y; SW_SPST_EVQQ2
S12: 1; SW_SPST_EVQQ2
S13: 9; SW_SPST_EVQQ2
S14: CLEAR; SW_SPST_EVQQ2
S15: B; SW_SPST_EVQQ2
S16: J; SW_SPST_EVQQ2
S17: R; SW_SPST_EVQQ2
S18: Z; SW_SPST_EVQQ2
S19: 2; SW_SPST_EVQQ2
S20: COLON; SW_SPST_EVQQ2
S21: BREAK; SW_SPST_EVQQ2
S22: C; SW_SPST_EVQQ2
S23: K; SW_SPST_EVQQ2
S24: S; SW_SPST_EVQQ2
S25: UP; SW_SPST_EVQQ2
S26: 3; SW_SPST_EVQQ2
S27: SEMICOLON; SW_SPST_EVQQ2
S29: D; SW_SPST_EVQQ2
S30: L; SW_SPST_EVQQ2
S31: T; SW_SPST_EVQQ2
S32: DOWN; SW_SPST_EVQQ2
S33: 4; SW_SPST_EVQQ2
S34: COMMA; SW_SPST_EVQQ2
S36: E; SW_SPST_EVQQ2
S37: M; SW_SPST_EVQQ2
S38: U; SW_SPST_EVQQ2
S39: LEFT; SW_SPST_EVQQ2
S40: 5; SW_SPST_EVQQ2
S41: MINUS; SW_SPST_EVQQ2
S43: F; SW_SPST_EVQQ2
S44: N; SW_SPST_EVQQ2
S45: V; SW_SPST_EVQQ2
S46: RIGHT; SW_SPST_EVQQ2
S47: 6; SW_SPST_EVQQ2
S48: PERIOD; SW_SPST_EVQQ2
S50: G; SW_SPST_EVQQ2
S51: O; SW_SPST_EVQQ2
S52: W; SW_SPST_EVQQ2
S53: SPACE; SW_SPST_EVQQ2
S54: 7; SW_SPST_EVQQ2
S55: SLASH; SW_SPST_EVQQ2
S56: LSHIFT; SW_SPST_EVQQ2
S57: RSHIFT; SW_SPST_EVQQ2

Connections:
PA0: J1.1, S1.1, S8.1, S15.1, S22.1, S29.1, S36.1, S43.1, S50.1
PA1: J1.2, S2.1, S9.1, S16.1, S23.1, S30.1, S37.1, S44.1, S51.1
PA2: J1.4, S3.1, S10.1, S17.1, S24.1, S31.1, S38.1, S45.1, S52.1
PA3: J1.5, S4.1, S11.1, S18.1, S25.1, S32.1, S39.1, S46.1, S53.1
PA4: J1.6, S5.1, S12.1, S19.1, S26.1, S33.1, S40.1, S47.1, S54.1
PA5: J1.7, S6.1, S13.1, S20.1, S27.1, S34.1, S41.1, S48.1, S55.1
PA6: J1.8, S7.1, S14.1, S21.1, S56.1, S57.1
PB0: J1.9, S1.2, S2.2, S3.2, S4.2, S5.2, S6.2, S7.2
PB1: J1.10, S8.2, S9.2, S10.2, S11.2, S12.2, S13.2, S14.2
PB2: J1.11, S15.2, S16.2, S17.2, S18.2, S19.2, S20.2, S21.2
PB3: J1.12, S22.2, S23.2, S24.2, S25.2, S26.2, S27.2
PB4: J1.13, S29.2, S30.2, S31.2, S32.2, S33.2, S34.2
PB5: J1.14, S36.2, S37.2, S38.2, S39.2, S40.2, S41.2
PB6: J1.15, S43.2, S44.2, S45.2, S46.2, S47.2, S48.2
PB7: J1.16, S50.2, S51.2, S52.2, S53.2, S54.2, S55.2, S56.2, S57.2

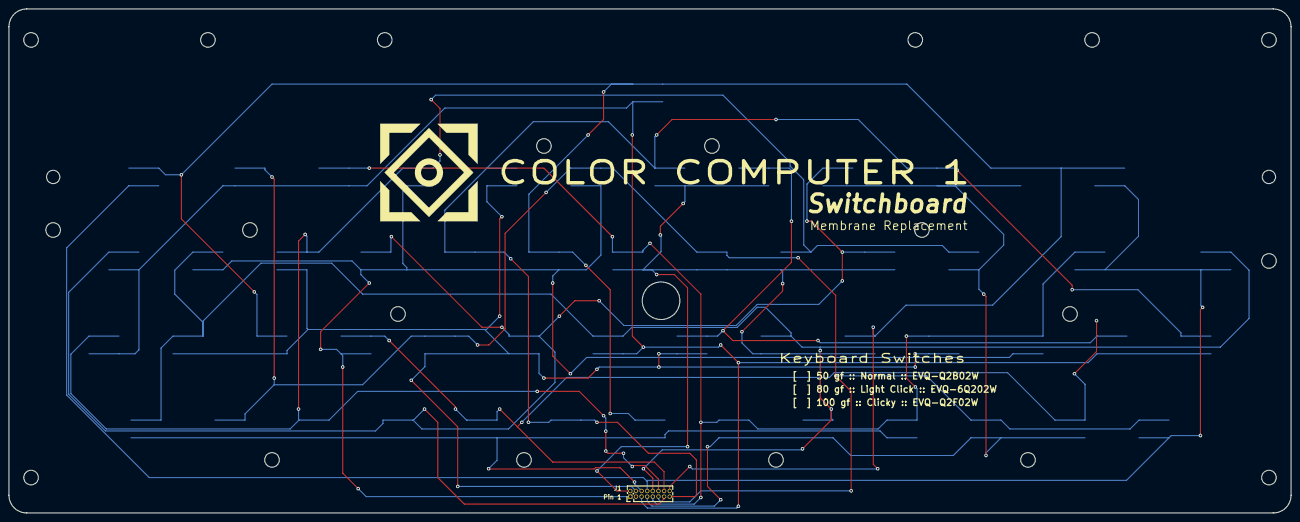
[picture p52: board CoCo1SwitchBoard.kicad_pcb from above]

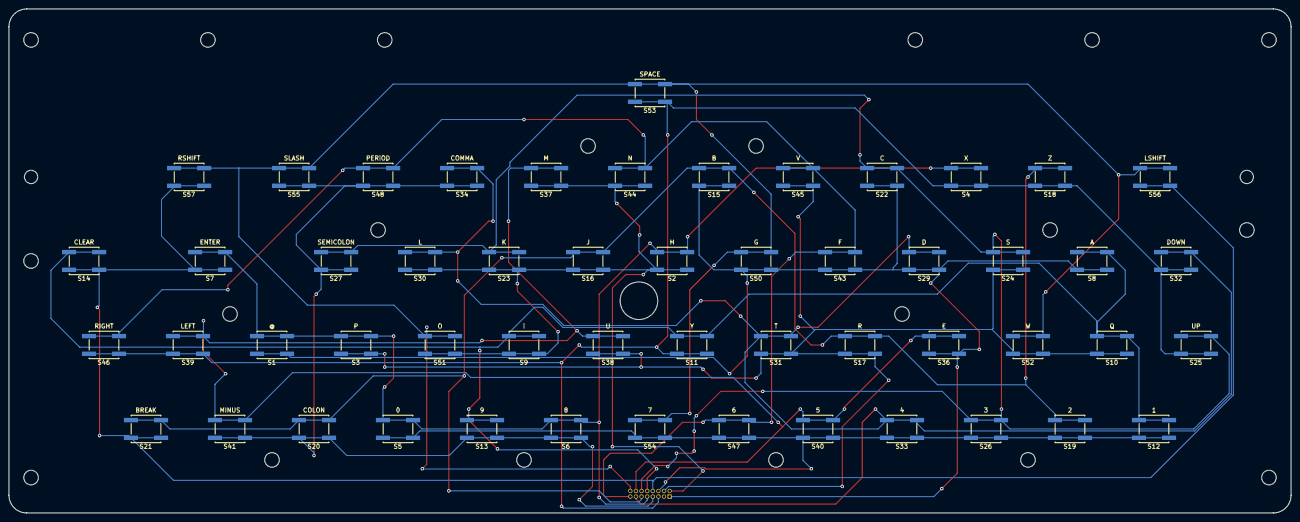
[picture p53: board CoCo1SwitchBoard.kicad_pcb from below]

Board: 2 copper layers, 290.0 x 114.0 mm, 54 parts (53 on the bottom side), 15 nets.

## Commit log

2022-08-15 Added CoCo1 image of board
2022-09-06 New Spacer Design
    [Coco2Spacer-Left.stl, Coco2Spacer-Right.stl, Kailh Choc Low Profile Switch.step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]
2022-09-06 New Spacer Design for CoCo2
    [Coco2Spacer-NewDesign.stl]
2022-09-09 Added New Spacer Errata
2023-02-24 Added Edge Connector and updated Documentation
    [Coco1-Spacer.stl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]
